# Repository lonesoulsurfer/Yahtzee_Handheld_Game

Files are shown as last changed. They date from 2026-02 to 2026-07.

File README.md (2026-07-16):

# Yahtzee - Handheld Game with an Optimal AI Brain

YouTube - https://youtu.be/DMBQGAXjRF4

Instructables - https://www.instructables.com/Yahtzee-Raspberry-Pi-Handheld-Game/

EKBK0852
RZYY5395
JPOU3428

---

## Two Versions of the Firmware

There are two versions of the game engine's "brain", and both are available to download and try from this repo:

- **V1, the Machine Learning brain.** The original approach: hand-built heuristics, probability tables, and a set of weighted priorities that adjust over time through self-play, stored in EEPROM. See the [V1 Overview](#v1-overview-the-machine-learning-brain) below.
- **V2, the Optimal "V-Brain".** The current version, and the one the rest of this README focuses on. It replaces the learned weights with an exact, mathematically solved decision table. See [How V2 Works](#how-v2-works-the-optimal-v-brain) below.

Both firmware versions are fully playable and included in this repo (`Yahtzee_v1.ino` / `Yahtzee_v2.ino`) if you want to compare them, or if you just prefer the adaptive feel of V1.

---

## V1 Overview: The Machine Learning Brain

V1 started out rule based, then grew into a probability and weights system. It uses hardcoded probability tables (for straights and of-a-kinds) to work out expected value, then adjusts its priorities, things like Yahtzee chasing, upper bonus feasibility, and endgame aggression, using a set of learned weights. Those weights live in EEPROM and shift over time based on self-play (the "Train AI" tool runs four personality variants against each other) and on how the human opponent plays.

It's a genuinely adaptive system. It gets tougher the more you play it, and it reads your playing style to adjust its own. But it's still fundamentally an approximation: the weights are a best guess at what matters in a given situation, tuned by trial and error rather than worked out from the actual maths of the game, and it needs a run-up of games before its learned behaviour is any good.

---

## How V2 Works: The Optimal V-Brain

V2 throws out the heuristics and weights entirely and replaces them with an exact solution, worked out once using dynamic programming and baked into a lookup table (`vtable.h`) that ships with the firmware. Rather than estimating the best move, V2 looks up the true expected value of every possible decision for the exact game state it's in, and simply picks the best one.

### The Value Table

`vtable.h` contains a solved value for every combination of:
- Which of the 13 scoring categories are still open (the "scorecard mask")
- The current upper section running total (capped at 63, since anything beyond that doesn't matter to the bonus)
- Whether a Yahtzee has already been scored (which changes what future Yahtzees are worth, thanks to the 100 point bonus)

For any of those states, the table gives the true expected final score from that point onward, assuming optimal play. This was worked out offline by starting from the end of the game and working backwards (a classic dynamic programming approach), so every value in the table is provably correct, not estimated.

### Making a Decision

On every roll, the V-brain does the following:
1. Sorts the current dice and looks up which of the 252 possible dice states it's in.
2. For each way it could hold some subset of the dice, works out the expected value of rerolling the rest, by weighting every possible reroll outcome by its true probability and looking up the resulting value in the table.
3. Compares that against simply stopping and scoring the best available category right now.
4. Picks whichever option has the higher expected value. No weights, no priority list, just the actual numbers.

This same lookup approach handles category selection too. Once the game engine stops rolling, it checks the value of scoring in every open category and takes the one with the highest true expected value, correctly accounting for the upper section bonus and the cost of spending a good category on a mediocre roll.

### Why It's Better

V1's weights can only ever approximate optimal play, and they need games (and EEPROM wear) to converge toward something good. V2's table already is the optimal policy. There's nothing to learn or converge toward, so it plays at maximum strength from the very first roll of the very first game, every single game. The trade-off is that V2 no longer profiles or adapts to a specific human opponent the way V1's learning system did. It isn't trying to be adaptive, it's trying to be correct.

### Still Carried Over from V1

A few things didn't need reinventing, so V2 keeps them as is:
- **Timeout protection.** If the game engine takes more than 30 seconds to decide, a watchdog forces it to pick the best available category and resets its state, so the game can never hang.
- **Stats tracking.** Win/loss history, high scores, and Yahtzee counts are still tracked and stored in EEPROM for the stats screens, even though none of it feeds back into how the V-brain plays.

---

## A Note on God Mode / Difficulty

V1's Normal / Hard / God Mode difficulty levels changed how aggressively the game engine would reroll. In V2, difficulty no longer changes how the AI plays. The V-brain always plays the mathematically optimal move, since there's no such thing as a "more optimal than optimal" setting. It is still beatable, since Yahtzee has a meaningful luck component, but you're playing against the best possible strategy on every roll.

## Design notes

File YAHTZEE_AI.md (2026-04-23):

# How the Yahtzee AI Works

When I first went on the journey to add a Player 1 vs the Computer mode, I didn't think it would take me down such a deep rabbit hole. The game of Yahtzee is a game of subtle nuances that revealed themselves to me when I tried (and still trying) to make an AI **God Mode** — an unbeatable opponent that always knows the right rolls and holds, and could use probability, strategy and learned weights to never lose.

The below is an outline of where I am currently.

---

## In a Nutshell

The AI holds dice based on what it's closest to completing, always thinking about whether the potential reward is worth the risk of rerolling. It respects special categories like Yahtzee and Large Straight enough to keep chasing them even late in a roll. It gets smarter the more you play against it, gradually learning what tends to win and adjusting its priorities accordingly. And at higher difficulties, it's simply more willing to gamble on a better outcome rather than accepting a safe but mediocre score.

---

## The Big Picture

The AI isn't just picking randomly or following a simple checklist. It's constantly asking itself two questions on every turn:

> *"Which dice should I keep?"*
> *"Is what I have now worth stopping for, or should I roll again?"*

Everything it does flows from trying to answer those two questions as smartly as possible.

---

## How It Decides Which Dice to Hold

Think of the AI like a card player who's always looking at their hand and asking *"what am I closest to completing?"* It looks at the dice and runs through a mental checklist, roughly in this order:

1. **Is the game almost over?** If there are only 2–3 scoring boxes left to fill, it stops being flexible and commits completely to whatever it still needs — chasing a Yahtzee, holding a straight sequence, or locking in pairs for a Full House. Crucially, it uses the actual remaining categories to decide what to hold — it won't hold two different numbers if neither remaining category can use them.

2. **Are we close to the upper section bonus?** The +35 bonus for scoring 63+ points in the top half of the scorecard is huge. If the AI is getting close, it'll often prioritise holding dice that help fill those upper boxes (Ones through Sixes), even if it means passing on something flashy.

3. **What's the best hand it's sitting on?** It looks at whether it has four-of-a-kind, three-of-a-kind, a pair, or a run of consecutive numbers, and figures out which is worth developing. It doesn't just hold the *"most dice"* — it asks which hand is actually worth the most if completed. Four 1s sounds like a lot to hold, but if the Ones box is already filled and Yahtzee is still available, it'll go for Yahtzee instead.

> **Key rule:** Pairs beat nothing, but a straight run beats a pair. If you have `2-3-4-5` showing, the AI will completely ignore any pair and hold the run, because straights are worth a flat 30 or 40 points — more predictable and often more valuable than building three-of-a-kind from a low pair.

---

## Probability Tables and Expected Value

Rather than using gut feel, the AI uses hardcoded probability tables to calculate the exact odds of completing any hand from its current dice. These are precomputed two-dimensional tables:

| Table | Description |
|---|---|
| **Of-a-Kind** | Probability of hitting 2-, 3-, 4-, or 5-of-a-kind when rerolling a specific number of dice (e.g. holding 3-of-a-kind and rerolling 2 dice has ~7.4% chance of hitting 5-of-a-kind in one roll) |
| **Large Straight** | Probability of completing a Large Straight based on how many values are still missing and how many rolls remain |
| **Small Straight** | Same as above for Small Straight |

For each possible way to hold the dice, the AI computes an **Expected Value (EV)** — the average score it can realistically expect if it plays that way. It then picks whichever hold pattern produces the highest EV, adjusted by the learned weights described below. This EV approach is the core engine; everything else either feeds into it or overrides it when warranted.

---

## Locked Decisions: When EV Doesn't Apply

Some situations are so mathematically clear that the AI locks the decision before any EV comparison or opponent-model adjustment is allowed to interfere:

- **4-of-a-kind with Yahtzee open** → Always reroll the 5th die
- **3-of-a-kind with Yahtzee open (or high value)** → Always hold the triple and chase the 4th (and potentially 5th) match
- **Yahtzee or Large Straight already in hand** → Always stop
- **Small Straight in hand with Large Straight already used** → Always stop and bank the guaranteed 30 points

These decisions set a `decision made` flag that prevents any downstream logic — conservative overrides, endgame risk adjustments, trailing/leading adjustments — from cancelling them.

---

## How It Decides Whether to Roll Again

- **After the first roll**, it almost always rerolls. Unless it rolled a Yahtzee or Large Straight right out of the gate, it's rolling again. There's also a minimum score floor: on the first roll, the AI won't stop unless it has 35+ points in hand (40+ on God Mode).

- **After the second roll**, it gets more selective. A confirmed Full House or solid upper box score is enough to stop — but four-of-a-kind with Yahtzee available, or four in a row with Large Straight available, always earns that third roll.

- **It also reads the score.** If the AI is losing by a decent amount, it plays more aggressively. If it's comfortably ahead, it locks in reliable points.

### Difficulty Margins

| Difficulty | Reroll Condition |
|---|---|
| **Normal** | EV of rerolling must exceed current score by at least 3 points |
| **Hard** | EV must match or exceed current score (break-even is enough) |
| **God Mode** | Will reroll even if EV is slightly *lower* — always chasing the maximum |

---

## The Three Difficulty Levels

| Level | Style | Base Aggression |
|---|---|---|
| **Normal** | Solid but forgiving. Stops if it has a decent score, won't chase long shots. | 0.35 |
| **Hard** | More aggressive. Willing to reroll a decent hand for something better. Uses learned data to adjust aggressiveness dynamically. | 0.65 |
| **God Mode** | Almost never stops after one roll. Squeezes every last roll out of every turn. Very tough to beat consistently. | 0.95 |

---

## Exploration vs Exploitation

About **10% of games**, the AI deliberately plays differently from its learned "best" strategy — this is an **exploration game**. It picks a random strategy (conservative or aggressive) with a randomised aggressiveness weight between 0.3 and 0.9.

The other **90% of games** it sticks to what's been working best — this is **exploitation**.

This balance ensures the AI doesn't get permanently stuck doing the same thing if something slightly different would actually work better.

---

## How It Learns Over Time

This is where it gets interesting — the AI actually remembers how past games went and slowly adjusts its behaviour. All learning data is saved to the device's **EEPROM** (non-volatile flash memory), so it persists even after you turn it off. A checksum is stored alongside the data so the device can detect and recover from any corruption.

Here's what it tracks and learns from:

- **What scores tend to lead to wins** — If games where it scores a Large Straight tend to go well, it prioritises Large Straights more. These preferences are stored as weight values per category type.

- **Confidence scaling** — Each weight adjustment is scaled by how many data points back it up. A weight based on 50 games carries four times more authority than one based on 5 games.

- **Whether rerolling was worth it — by score bracket** — It tracks reroll outcomes in four buckets (0–9, 10–19, 20–29, 30+) and builds a picture of when rerolling pays off in each bracket.

- **How each specific hold pattern performs** — For every combination of dice value and count held (e.g. *"held two 5s"*, *"held three 6s"*), it records how often that pattern led to a score of 20 or more. Tracked in a 6×6 grid (values 1–6 × counts 1–5).

- **When chasing Yahtzee or straights historically pays off** — Separate success rate counters track every attempt and completion. If Yahtzee success rate falls below 12%, it tightens the entry threshold (only chases with 3+ matching dice). If it climbs above 28%, it gets more aggressive (will chase from just a pair with 2 rolls left).

- **Which hold count works best (0–5 dice held)** — Tracked and displayed in the stats screen; informs the big picture of how the AI is playing.

- **Endgame close-game outcomes** — From turn 11 onwards, if the game is within 20 points, the AI records whether it won or lost. If its close-game win rate falls below 45%, it becomes more aggressive in the final turns.

- **Chance category timing** — Chance is most valuable early when all other slots are open. The AI tracks when it scores Chance (turns 1–3, 4–6, 7–9, or 10–13) and how often each timing leads to a win.

- **Score position at turn 10** — Tracked as a running average of (AI score minus human score) at the halfway point. If the AI is consistently 20+ points behind at turn 10, it raises aggression on early rerolls.

- **Category timing** — For each of the 13 scoring categories, the AI tracks the average turn it tends to score that category and uses this to inform future category priority.

- **Your playing style** — The AI quietly tracks how you play:
  - How often you hit the upper bonus
  - How many Yahtzees you roll
  - How aggressive you are (reroll rate and chase attempts)
  - Your average score

  Against a **strong player** (avg. score over ~250) it plays harder, rerolling on scores it might otherwise accept. Against a **conservative player** it locks in moderate scores more readily. If you frequently score Yahtzees, the AI prioritises chasing its own Yahtzee more urgently.

---

## The Four Strategies It Tests Against Itself

When you use the **Train AI** option in the Tools menu, the AI plays against itself using four different personalities:

| Strategy | Style |
|---|---|
| **Aggressive** | Goes hard for Yahtzees and big straights, willing to sacrifice safe points |
| **Balanced** | Uses whatever it's currently learned as its best approach |
| **Conservative** | Prioritises guaranteed points and the upper bonus over risky special hands |
| **Experimental** | A slightly randomised version, trying things a bit differently each time |

After each batch of self-play games, it looks at which personality won the most and nudges its main strategy in that direction. It's a slow process — you won't see it transform overnight — but over dozens of games it genuinely does shift toward what's been working.

Each strategy variant stores its own set of 8 weight values alongside its performance record (wins, games played, total score). It mostly picks the variant with the best recent win rate, but occasionally gives the others a shot so they can keep accumulating data.

---

## Category Selection

Once the AI has decided to stop rolling, it chooses which scoring category to use:

- It calculates an **expected value for every open category** given the current dice.
- **Upper section categories** are weighted by a bonus feasibility score — if the 35-point bonus is still realistically achievable, upper slots get a boost proportional to how much they contribute toward hitting 63.
- It considers **opportunity cost** — using a high-value slot (like Sixes) for a weak result is penalised more than using a low-value slot (like Ones) for the same score.
- In the **final 1–2 turns**, category selection becomes critical: it won't squander a Yahtzee chase on a 3-of-a-kind slot, and it won't take Chance if a more targeted category is still reachable.

---

## What Gets Displayed in the Stats Screens

The **AI Statistics screen** (accessible from the Tools menu) shows six pages of data including:

- Overall win rate and score history
- Reroll improvement rates per score bracket
- Hold pattern frequency
- Endgame win rates in close games and blowouts
- The four strategy variant performances
- Chance category timing
- Turn-10 score position history
- Current live values of all 8 learned weights

The graphs also track early-game vs recent-game average score so you can see whether the AI is improving over time.

---

## Timeout Protection

If the AI ever gets into an unexpected state and takes more than **30 seconds** to make a decision, a watchdog timer forces it to pick the best available category immediately and resets its state. This prevents the game from ever hanging.

---

## A Note on God Mode

God Mode is the closest the AI gets to theoretically optimal Yahtzee play. It uses maximum aggression, the full probability tables, all learned weights, and never applies conservative overrides.

It **is** beatable — Yahtzee has a meaningful luck component — but it will consistently make the highest expected value decision available to it on every single roll.

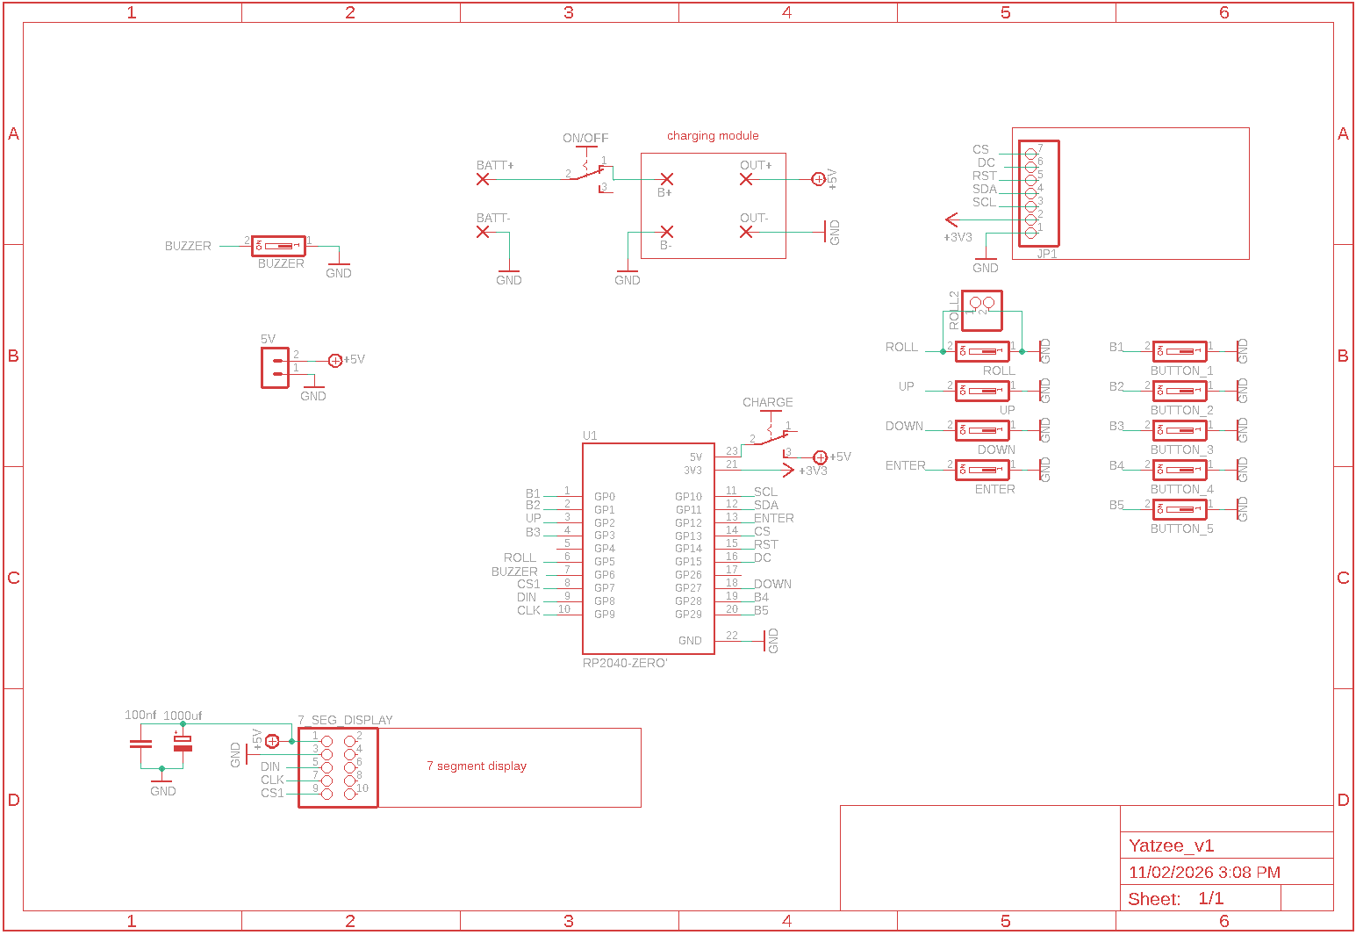
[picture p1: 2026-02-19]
Yahtzee - Schematic.png

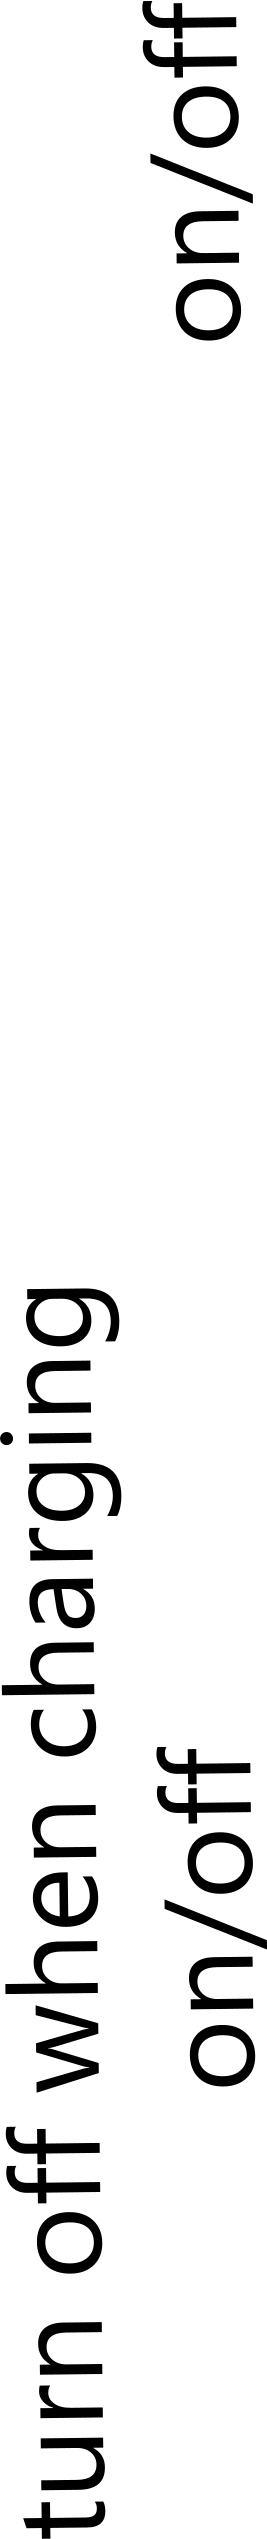
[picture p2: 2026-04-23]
Panel_Design/Back Panel/Yahtzee - Back Panel Inkscape.png

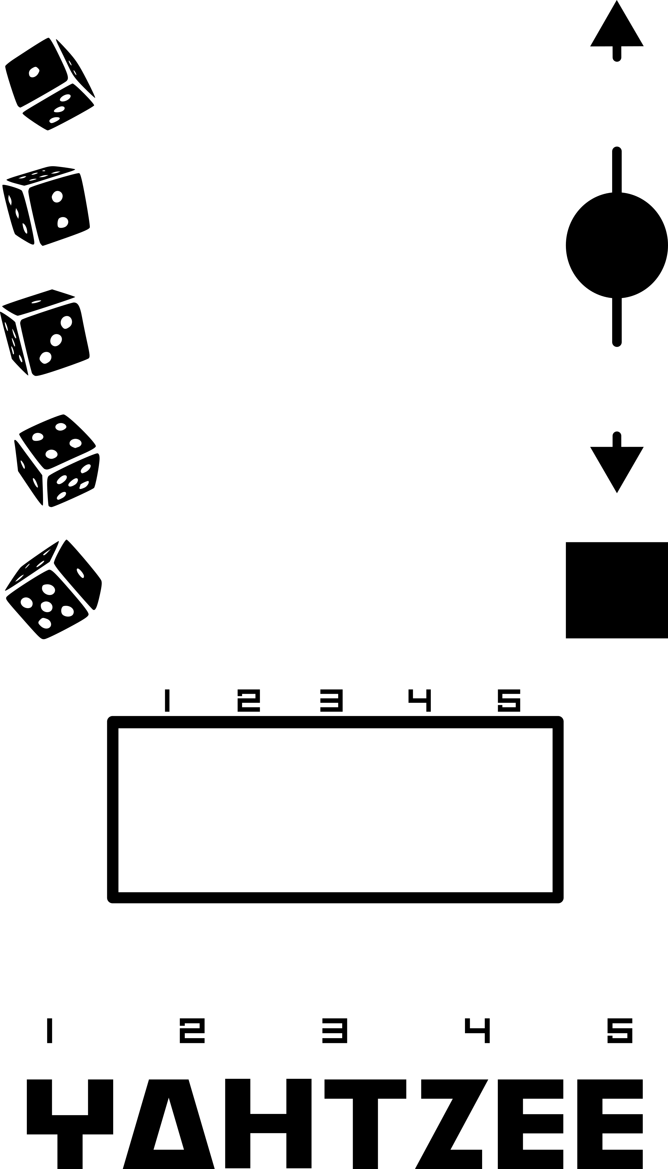
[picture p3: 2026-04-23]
Panel_Design/Front Panel/Front_Panel/Front Panel - Inkscape.png

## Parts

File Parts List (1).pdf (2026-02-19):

Part | Type | Part Number | Qty | Link | Image
Raspberry Pi Pico Zero | | | 1 | Link (https://www.aliexpress.com/w/wholesale-Raspberry-PI-Pico-Mini-RP2040%2525252dZERO-Microcontroller.html) Link (https://www.aliexpress.com/item/32949954569.html?curPageLogUid=Z8zhaCP7cIt1) Link (https://www.aliexpress.com/w/wholesale-TFT-Display-2.0-inch-OLED-LCD-Drive-IC-ST7789V-240.html)
Buzzer | Passive | | 1

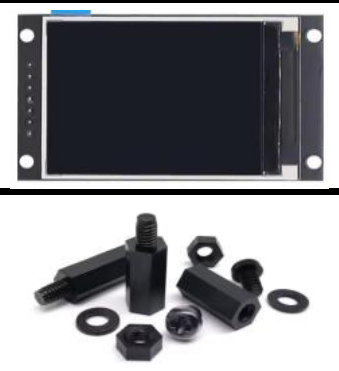
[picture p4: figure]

TFT Display | 2.0 inch OLED LCD Drive IC 240 x 320 | ST7789V | 1
Nylon Hex Spacers | M2 - assorted | | 1 | Link (https://www.aliexpress.com/item/1005007123661699.html)
Hex Socket Screw Kit | Ms - Assorted | DIN912 | 1 | Link (https://www.aliexpress.com/item/1005007273134914.html?curPageLogUid=XMboOUAJHQU8)
Battery | Lipo - (Mobile) | ab463446bu | 1 | Link (https://www.aliexpress.com/w/wholesale-ab463446bu.html?spm=a2g0o.detail.search.0)

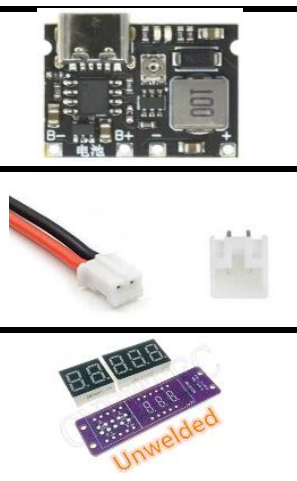
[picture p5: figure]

Charging & Voltage Module | 3.7V To 9V 5V 2A DC-DC Step Up Boost Modul | | 1 | Link (https://www.aliexpress.com/item/1005005656423941.html?srcSns=sns_More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)
Mini JST Connector and wire | 2 Pin | 1 | Link (https://vi.aliexpress.com/item/1005005939956886.html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)
7 segment display | 5 digit | 1 | Link (https://www.aliexpress.com/item/1005008537770484.html)

Part | Type | Part Number | Qty | Link | Image
Switches | Momentary. You can just use the reds ones if you want | SKRCADD010 | 7 | Link (https://www.aliexpress.com/w/wholesale-SKRCADD010.html?spm=a2g0o.productlist.search.0)
| | | 2 | Link (https://www.aliexpress.com/item/1005002904652943.html)
| slide | MSK-12D19 | 2 | Link (https://www.aliexpress.com/item/32828124825.html)
Capacitor | Polyester | 100nf | 1 | Link (https://vi.aliexpress.com/w/wholesale-capacitor-100nf.html?spm=a2g0o.productlist.search.0)
| Electrolytic | 1000uf | 1 | Link (https://www.aliexpress.com/item/1005007172225164.html?curPageLogUid=ffqTkzvnJ7Ic)
Header Pins | Female - short profile 7 rows | | | Link (https://www.aliexpress.com/item/1005004122312694.html)
| Male 7 rows | | | Link (https://www.aliexpress.com/w/wholesale-header-pin-male.html?spm=a2g0o.detail.search.0)

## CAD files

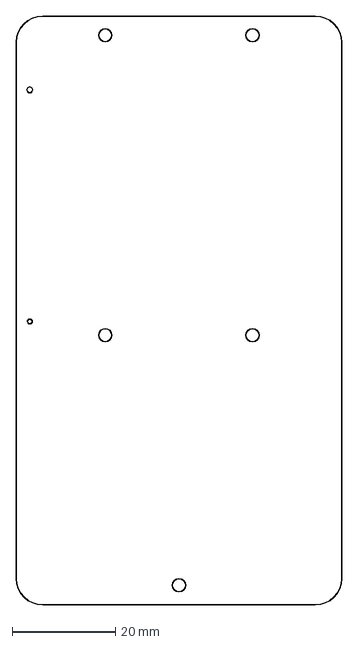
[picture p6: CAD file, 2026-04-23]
Panel_Design/Back Panel/Yatzee_PCB Back Panel Fusion.dxf
63.0 x 114.0 mm

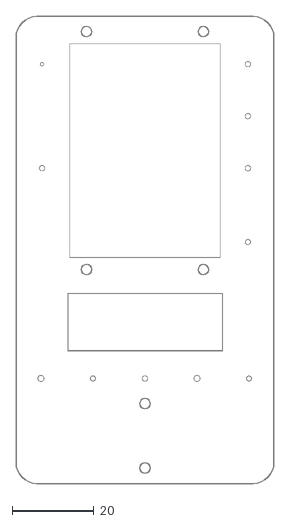
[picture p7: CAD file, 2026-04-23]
Panel_Design/Front Panel/Front_Panel/Yatzee PCB.dxf
63.0 x 114.0

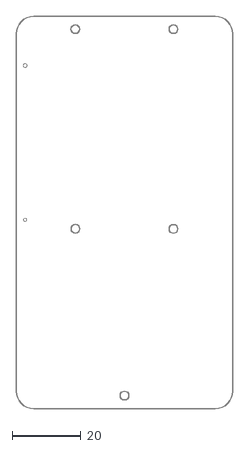
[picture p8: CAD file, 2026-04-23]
Panel_Design/Back Panel/Yatzee_PCB Back Panel.dxf
63.0 x 114.0

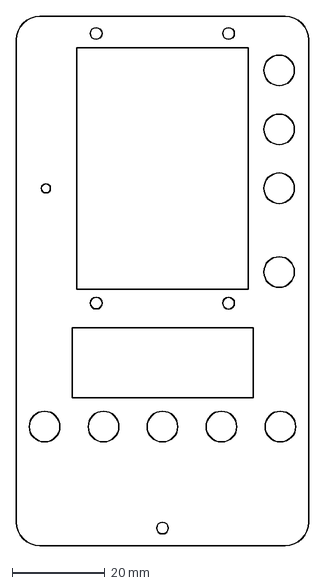
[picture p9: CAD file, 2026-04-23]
Panel_Design/Front Panel/Front_Panel/Yatzee Fusion.dxf
63.0 x 114.0 mm

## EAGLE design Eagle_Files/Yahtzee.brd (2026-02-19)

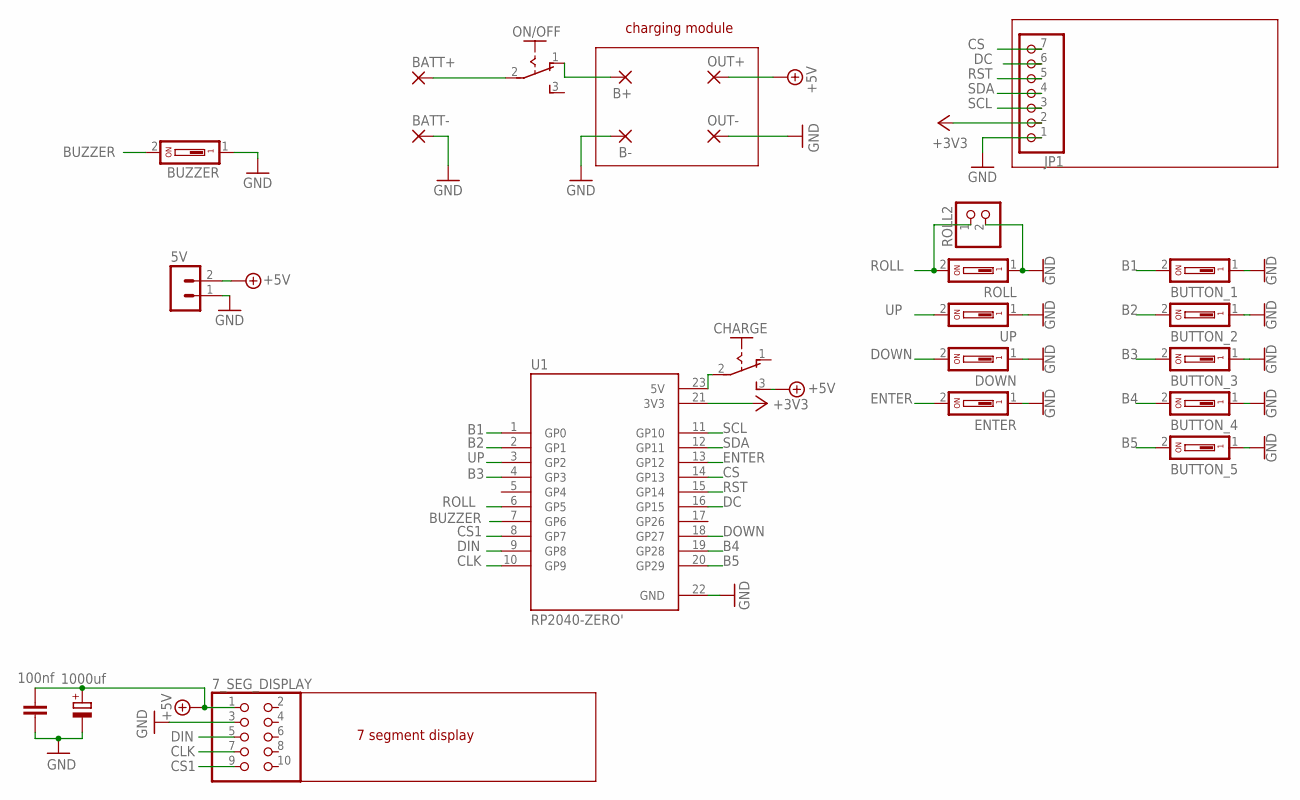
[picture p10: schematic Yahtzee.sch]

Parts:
5V: B2B-PH-K-S
7_SEG_DISPLAY: PINHD-2X5; 2X05
B+: SMD5; SMD2,54-5,08
B-: SMD5; SMD2,54-5,08
BATT+: SMD5; SMD2,54-5,08
BATT-: SMD5; SMD2,54-5,08
BUTTON_1, BUTTON_2, BUTTON_3, BUTTON_4, BUTTON_5: DS01; DS-01
BUZZER: DS01; DS-01
C1: 100nf; C050-024X044
C2: 1000uf; E2,5-7
CHARGE: M251
DOWN: DS01; DS-01
ENTER: DS01; DS-01
JP1: PINHD-1X7; 1X07
ON/OFF: M251
OUT+: SMD5; SMD2,54-5,08
OUT-: SMD5; SMD2,54-5,08
ROLL: DS01; DS-01
ROLL2: PINHD-1X2; 1X02
U1: RP2040-ZERO'; MODULE_RP2040-ZERO
UP: DS01; DS-01

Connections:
+3V3: JP1.2, U1.21 (3V3)
+5V: 5V.2, 7_SEG_DISPLAY.1, C1.1, C2.+, CHARGE.3 (S), OUT+.1
B1: BUTTON_1.2, U1.1 (GP0)
B2: BUTTON_2.2, U1.2 (GP1)
B3: BUTTON_3.2, U1.4 (GP3)
B4: BUTTON_4.2, U1.19 (GP28)
B5: BUTTON_5.2, U1.20 (GP29)
BUZZER: BUZZER.2, U1.7 (GP6)
CLK: 7_SEG_DISPLAY.7, U1.10 (GP9)
CS: JP1.7, U1.14 (GP13)
CS1: 7_SEG_DISPLAY.9, U1.8 (GP7)
DC: JP1.6, U1.16 (GP15)
DIN: 7_SEG_DISPLAY.5, U1.9 (GP8)
DOWN: DOWN.2, U1.18 (GP27)
ENTER: ENTER.2, U1.13 (GP12)
GND: 5V.1, 7_SEG_DISPLAY.3, B-.1, BATT-.1, BUTTON_1.1, BUTTON_2.1, BUTTON_3.1, BUTTON_4.1, BUTTON_5.1, BUZZER.1, C1.2, C2.-, DOWN.1, ENTER.1, JP1.1, OUT-.1, ROLL.1, ROLL2.2, U1.22 (GND), UP.1
unnamed: BATT+.1, ON/OFF.2
unnamed: B+.1, ON/OFF.1 (O)
unnamed: CHARGE.2, U1.23 (5V)
ROLL: ROLL.2, ROLL2.1, U1.6 (GP5)
RST: JP1.5, U1.15 (GP14)
SCL: JP1.3, U1.11 (GP10)
SDA: JP1.4, U1.12 (GP11)
UP: U1.3 (GP2), UP.2

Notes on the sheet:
charging module
7 segment display

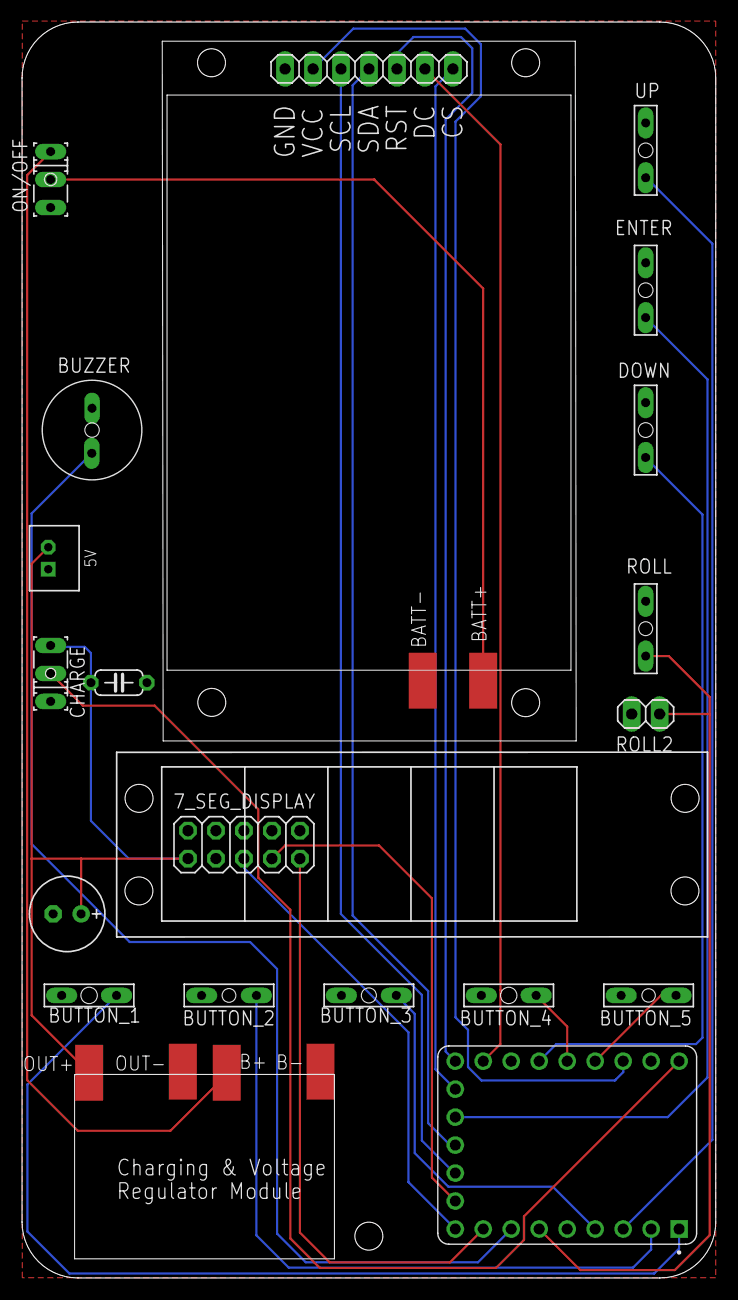
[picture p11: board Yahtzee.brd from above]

Board: 2 copper layers, 63.0 x 114.0 mm, 25 parts (0 on the bottom side), 24 nets.

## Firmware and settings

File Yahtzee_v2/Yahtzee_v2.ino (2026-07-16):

/*
 * Gameplay:
 * - 2 players alternate turns
 * - Each turn: Roll dice up to 3 times
 * - Hold dice between rolls with buttons 1-5
 * - After rolls, select scoring category
 * - Game ends after 26 turns (13 categories × 2 players)
 */

#include <SPI.h>
#include <Adafruit_GFX.h>
#include <Adafruit_ST7789.h>
#include <EEPROM.h>
#include "vtable.h"   // Optimal Yahtzee value table (option B). Must be in the sketch folder.

// ============================================================================
// BLACKJACK TYPES — defined here so Arduino prototype-generator sees them
// ============================================================================

struct Card {
  uint8_t value;  // 1=Ace 2-10 11=J 12=Q 13=K
  uint8_t suit;   // 0=Spades 1=Hearts 2=Diamonds 3=Clubs
};

const char* bjValueNames[] = {"A","2","3","4","5","6","7","8","9","10","J","Q","K"};

#define BJ_MAX_CARDS 11   // max cards in one BJ hand (same as original MAX_HAND)
#define MAX_HAND BJ_MAX_CARDS  // keep original name working in BJ file

int  bjDeckIndices[52];
int  bjDeckTop = 0;

Card bjPlayerHand[BJ_MAX_CARDS];
Card bjCompHand[BJ_MAX_CARDS];
Card bjSplitHand[BJ_MAX_CARDS];
int  bjPlayerCount = 0;
int  bjCompCount   = 0;
int  bjSplitCount  = 0;

enum BJGameState {
  BJ_STATE_MENU,
  BJ_STATE_BETTING,
  BJ_STATE_SIDEBET,
  BJ_STATE_PLAYER_TURN,
  BJ_STATE_COMP_TURN,
  BJ_STATE_RESULT,
  BJ_STATE_GAMEOVER
};

// Alias for side-bet screen (BJ file may reference BJ_STATE_SIDE_BETS)
#define BJ_STATE_SIDE_BETS BJ_STATE_SIDEBET

enum BJHandResult {
  BJ_RES_NONE,
  BJ_RES_PLAYER_BJ,
  BJ_RES_COMP_BJ,
  BJ_RES_PLAYER_WIN,
  BJ_RES_COMP_WIN,
  BJ_RES_PUSH,
  BJ_RES_PLAYER_BUST,
  BJ_RES_COMP_BUST
};

#define BJ_SB_COUNT 3

// ── EXACT EV LOOKUP TABLE (precomputed, 9.6KB flash) ─────────────────
// Auto-generated exact EV lookup table
// 252 dice states × 13 categories × 3 roll counts
// Values are EV × 2 (uint8, precision 0.5pts, max 50pts)
// State index: use lookupStateIndex(sorted_dice)

// Sorted dice states (for index lookup)
const uint8_t EV_STATES[252][5] = {
  {1,1,1,1,1},
  {1,1,1,1,2},
  {1,1,1,1,3},
  {1,1,1,1,4},
  {1,1,1,1,5},
  {1,1,1,1,6},
  {1,1,1,2,2},
  {1,1,1,2,3},
  {1,1,1,2,4},
  {1,1,1,2,5},
  {1,1,1,2,6},
  {1,1,1,3,3},
  {1,1,1,3,4},
  {1,1,1,3,5},
  {1,1,1,3,6},
  {1,1,1,4,4},
  {1,1,1,4,5},
  {1,1,1,4,6},
  {1,1,1,5,5},
  {1,1,1,5,6},
  {1,1,1,6,6},
  {1,1,2,2,2},
  {1,1,2,2,3},
  {1,1,2,2,4},
  {1,1,2,2,5},
  {1,1,2,2,6},
  {1,1,2,3,3},
  {1,1,2,3,4},
  {1,1,2,3,5},
  {1,1,2,3,6},
  {1,1,2,4,4},
  {1,1,2,4,5},
  {1,1,2,4,6},
  {1,1,2,5,5},
  {1,1,2,5,6},
  {1,1,2,6,6},
  {1,1,3,3,3},
  {1,1,3,3,4},
  {1,1,3,3,5},
  {1,1,3,3,6},
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
};

// EV table: [state_index][category][rolls_remaining]
// Category: 0-5=upper, 6=3K, 7=4K, 8=FH, 9=SmSt, 10=LgSt, 11=Ytz, 12=Chance
// Rolls: 0=must score now, 1=one roll left, 2=two rolls left
// ─────────────────────────────────────────────────────────────────────


BJGameState  bjGameState  = BJ_STATE_MENU;
BJHandResult bjHandResult = BJ_RES_NONE;

int      bjCredits       = 200;
int      bjBet           = 10;
uint32_t bjHandsPlayed   = 0;
int      bjPlayerWins    = 0;
int      bjCompWins      = 0;
int      bjPushes        = 0;
uint32_t bjLifetimeWon   = 0;
uint32_t bjLifetimeBet   = 0;
bool     bjPlayerIsDealer = true;
int      bjLastPayout    = 0;
int      bjLastNetResult = 0;
int      bjBiggestWin    = 0;
bool     bjDoubledDown   = false;
bool     bjIsSplit       = false;
int      bjSplitHandIdx  = 0;
int      bjSplitBet      = 0;
BJHandResult bjSplitResult = BJ_RES_NONE;

int  bjSideBetAmount[BJ_SB_COUNT] = {0, 0, 0};
int  bjSideBetPayout[BJ_SB_COUNT] = {0, 0, 0};
bool bjSideBetWon[BJ_SB_COUNT]    = {false, false, false};
int  bjSbSelected  = 0;
bool bjSbAdjusting = false;
BJGameState bjSbReturnState = BJ_STATE_BETTING;
const char* bjSbNames[BJ_SB_COUNT] = { "Perfect Pairs", "21 + 3", "Lucky Lucky" };

// REAL BJAILearning struct (fields match Blackjack_V1.ino exactly)
struct BJAILearning {
  uint16_t wins;
  uint16_t games;
  uint16_t hit16wins;
  uint16_t hit16total;
  uint16_t stand16wins;
  uint16_t stand16total;
  uint8_t  softAdj;
} aiData;


// ============================================================================
// PIN DEFINITIONS
// ============================================================================

// ST7789 TFT Display (Hardware SPI1)
#define TFT_CS     13  // GP13
#define TFT_RST    14  // GP14 (RES on display)
#define TFT_DC     15  // GP15
// Hardware SPI1 uses:
// MOSI (SDA) - GP11 (SPI1 TX) - already correct!
// SCLK (SCL) - GP10 (SPI1 SCK) - already correct!

// MAX7219 5-digit 7-segment display
#define DIN_PIN 8   // GP8 (swapped)
#define CLK_PIN 9   // GP9 (swapped)
#define CS_PIN  7   // GP7

// Buzzer
#define BUZZER_PIN 6   // GP6

// Button pins
const int holdButtons[] = {29, 28, 3, 1, 0};  // Hold dice 1-5 (reversed for 5-digit display)
const int rollButton = 5;        // GP5
const int upButton = 2;          // GP2
const int downButton = 27;       // GP27
const int enterButton = 12;      // GP12

#define EEPROM_BRIGHTNESS_ADDR 0  // EEPROM address for brightness storage
#define EEPROM_SOUND_ADDR 1       // EEPROM address for sound on/off
#define EEPROM_VOLUME_ADDR 11     // EEPROM address for volume (1 byte: 1-3)
#define EEPROM_HIGH_SCORE_ADDR 2  // EEPROM address for high score (2 bytes)
#define EEPROM_P1_WINS_ADDR 4     // EEPROM address for P1 wins (2 bytes)
#define EEPROM_P2_WINS_ADDR 6     // EEPROM address for P2 wins (2 bytes)
#define EEPROM_TIES_ADDR 8        // EEPROM address for ties (2 bytes)
#define EEPROM_MOST_YAHTZEES_ADDR 10  // EEPROM address for most Yahtzees in one game (1 byte)
#define EEPROM_AI_SPEED_ADDR 12       // EEPROM address for AI speed (1 byte: 0-3)
#define EEPROM_TFT_BRIGHTNESS_ADDR 13 // EEPROM address for TFT brightness (1 byte: 1-10)
#define EEPROM_AUTO_ADVANCE_ADDR 14   // EEPROM address for auto-advance (1 byte: 0/1)
#define EEPROM_AI_DIFFICULTY_ADDR 15  // EEPROM address for AI difficulty (1 byte: 0=Normal, 1=Hard, 2=God Mode)
#define EEPROM_AI_LEARNING_START 1000   // EEPROM address for AI learning data (moved far from other data)
#define EEPROM_STRATEGY_VARIANTS_ADDR 2048  // EEPROM address for 4 strategy variants (moved to 2048 to give AI data 1024 bytes)
#define EEPROM_AGGR_WEIGHT_ADDR 2112        // Per-difficulty aggressiveness weights: 3 bytes (Normal=0, Hard=1, God=2)
                                            // Stored as uint8_t * 100 (e.g. 0.65 → 65)

// ============================================================================
// DISPLAY INITIALIZATION
// ============================================================================

// Hardware SPI1 for TFT (much faster!)
Adafruit_ST7789 tft = Adafruit_ST7789(&SPI1, TFT_CS, TFT_DC, TFT_RST);

// ============================================================================
// GAME STATE VARIABLES
// ============================================================================

int dice[5];              // Current dice values (1-6)
bool held[5];             // Which dice are held
int currentPlayer = 1;    // Current player (1 or 2)
int rollsLeft = 3;        // Rolls remaining this turn
int rollsUsedThisTurn = 0;  // Track actual rolls used (1, 2, or 3)
int turn = 1;             // Current turn number (1-26)
int playerTurn = 1;       // Current player's turn number (1-13)
int scores1[13];          // Player 1 scores (-1 = unused)
int scores2[13];          // Player 2 scores (-1 = unused)
int yahtzeeBonus1 = 0;    // Player 1 Yahtzee bonus count
int yahtzeeBonus2 = 0;    // Player 2 Yahtzee bonus count
bool gameOver = false;    // Game finished flag
// Per-game roll count for AI: tracks how many times each roll-count (1/2/3)
// was used THIS game so rollCountWins credits the correct distribution.
uint16_t aiRollCountThisGame[4] = {0,0,0,0};  // indices 1-3 used


// UI state
enum GameState {
  STATE_INTRO,            // Animated intro screen (NEW!)
  STATE_MENU,             // Main menu (NEW!)
  STATE_START,            // Waiting to start turn
  STATE_ROLLING,          // Rolling dice phase
  STATE_CATEGORY_SELECT,  // Selecting score category
  STATE_GAME_OVER         // Game finished
};
GameState gameState = STATE_START;

// Menu state
int selectedMenuItem = 0;  // 0 = 2 Player, 1 = vs Computer, 2 = Tools
bool vsComputer = false;   // Track if playing against computer
bool inToolsMenu = false;  // Track if we're in the tools submenu
bool inSoundMenu = false;  // Track if we're in the sound submenu
bool inHelpMenu = false;   // Track if we're in the help/rules screen
bool inGraphMenu = false;  // Track if we're in the AI graphs screen
bool inAIDifficultyMenu = false;  // Track if we're in the AI difficulty selection menu
int selectedAIDifficulty = 1;  // Selected difficulty in the menu (0=Normal, 1=Hard, 2=God)
int helpPage = 0;          // Help screen page (0-2)
int toolsPage = 0;         // Tools menu page (0 = page 1, 1 = page 2)
int selectedToolItem = 0;  // 0=7seg, 1=sound, 2=auto-advance, 3=stats, 4=AI stats, 5=AI speed, 6=export, 8=graphs, 9=help, 10=back
int selectedSoundItem = 0; // 0 = Sound On/Off, 1 = Volume, 2 = Back
int aiStatsPage = 0;  // single AI Stats page
int graphPage = 0;    // Graph page: 0-5 for 6 enhanced analysis graphs
int max7219Brightness = 8;  // Brightness level (0-15, loaded from EEPROM in setup)
bool adjustingBrightness = false;  // Track if actively adjusting brightness
int tftBrightness = 10;     // TFT brightness level (1-10, loaded from EEPROM in setup)
bool adjustingTftBrightness = false;  // Track if actively adjusting TFT brightness
bool soundEnabled = true;  // Sound on/off (loaded from EEPROM in setup)
int volume = 2;  // Volume level (1-3, loaded from EEPROM in setup)
bool adjustingVolume = false;  // Track if actively adjusting volume
bool autoAdvance = false;  // Auto-advance to next turn after scoring (loaded from EEPROM in setup)

// Game over animation state
#define MAX_CONFETTI 40
struct Confetti {
  float x;
  float y;
  float speedY;
  float speedX;
  uint16_t color;
  bool active;
};
Confetti confetti[MAX_CONFETTI];
unsigned long gameOverStartTime = 0;
bool gameOverAnimationStarted = false;
float winnerTextScale = 0.0;  // For dramatic entrance
uint16_t winnerColorHue = 0;  // For color cycling

// Statistics variables
int highScore = 0;        // Highest score ever
int p1Wins = 0;           // Player 1 total wins
int p2Wins = 0;           // Player 2 total wins
int totalTies = 0;        // Total tied games
int mostYahtzees = 0;     // Most Yahtzees in one game
int currentGameYahtzees1 = 0;  // Yahtzees this game for P1
int currentGameYahtzees2 = 0;  // Yahtzees this game for P2
int aiDifficulty = 1;  // AI difficulty: 0 = Normal, 1 = Hard, 2 = God Mode
int aiSpeed = 2;  // AI speed: 0=Slow (5s), 1=Medium (3.5s), 2=Fast (2.5s), 3=Instant (0.5s)

// Per-game tracking for new decision-quality stats
int  aiChanceBucket           = -1;   // Which turn-bucket Chance was scored in (-1=not yet)
int  aiChanceVsUpperLastChoice = -1;  // 0=chose upper, 1=chose Chance, -1=no decision yet
bool aiSacrificedSlot[6]  = {false,false,false,false,false,false}; // Which upper slots were sacrificed
bool aiAheadAtTurn10      = false; // Was AI ahead at turn 10?
bool aiTurn10Recorded     = false; // Have we recorded turn-10 state this game?

// ============================================================================
// AI LEARNING SYSTEM
// ============================================================================

// AI Learning data structure - stores performance metrics in EEPROM
// Strategy variant structure - MUST be defined before AILearningData

// Analyze straight potential and return hold strategy


// Decision outcome tracking
struct DecisionOutcome {
  uint8_t turnNumber;        // Which turn (1-13)
  uint8_t rollNumber;        // Which roll (1-3)
  uint8_t diceHeld;          // How many dice held (0-5)
  uint8_t categoryScored;    // Which category was scored (0-12)
  uint8_t pointsScored;      // How many points
  bool wonGame;              // Did AI win this game?
  bool leadingWhenDecided;   // Was AI leading when decision made?
};

// Track last 100 decisions for pattern analysis
#define MAX_DECISION_HISTORY 100
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
void loop() {
  static unsigned long lastButtonCheck = 0;
  static unsigned long lastAnimFrame = 0;
  
  // Update intro animation at 60fps
  if(gameState == STATE_INTRO) {
    static bool startupMusicPlayed = false;
    static unsigned long introStartTime = 0;
    
    if(introStartTime == 0) {
      introStartTime = millis();
    }
    
    if(millis() - lastAnimFrame > 16) {  // ~60fps
      lastAnimFrame = millis();
      
      // Play startup music after 100ms delay (so dice are visible and falling)
      if(!startupMusicPlayed && millis() - introStartTime > 100) {
        buzzerStartupTune();
        startupMusicPlayed = true;
      }
      
      updateIntroAnimation();
      
      // Always redraw if not complete (to show title animation)
      if(!introComplete) {
        drawIntroScreen();
      } else {
        // Transition to menu after a short pause so YAHTZEE is readable
        static unsigned long completeTime = 0;
        static bool drewComplete = false;
        
        if(!drewComplete) {
          drawIntroScreen();
          completeTime = millis();
          drewComplete = true;
        } else if(millis() - completeTime > 600) {
          // After 600ms, go to menu
          gameState = STATE_MENU;
          startupMusicPlayed = false;
          introStartTime = 0;
          drewComplete = false;   // Reset for next time
          completeTime = 0;
          drawScreen();
        }
      }
    }
  }

  // Update dice animation
  if(diceAnimating) {
    updateDiceAnimation();
    delay(16);  // ~60fps for smooth animation
  }
  
  // Update celebration particles
  // CRITICAL: Never run celebration once game is over — it overwrites the scorecard
  if(celebrationActive && gameState == STATE_GAME_OVER) {
    celebrationActive = false;  // Kill any active celebration when game ends
  }
  if(celebrationActive) {
    updateCelebration();
    drawCelebration();  // Draw clean celebration screen with particles
    delay(16);  // ~60fps for smooth animation
  }
  
  // Continuously animate the game over screen (winner badge floats each frame)
  static unsigned long lastGameOverFrame = 0;
  if(gameState == STATE_GAME_OVER && !celebrationActive && millis() - lastGameOverFrame > 16) {
    lastGameOverFrame = millis();
    drawGameOver();
  }
  
  // Handle computer turn - trigger automatically when it's Player 2's turn
  // **CRITICAL**: Don't run computer turn during celebrations!
  if(vsComputer && currentPlayer == 2 && 
     gameState != STATE_GAME_OVER && gameState != STATE_INTRO && gameState != STATE_MENU &&
     !celebrationActive) {  // NEW: Don't interrupt celebrations
    computerTurn();
  }
  
  // Check buttons every 100ms (only for human player)
  if(millis() - lastButtonCheck > 100) {
    lastButtonCheck = millis();
    if(!computerIsThinking) {
      // Full button processing for human player
      checkButtons();
    } else {
      // During AI turn, still allow UP/DOWN for viewing scores
      checkViewButtons();
    }
    lastButtonCheck = millis();
  }
  
  // Check for game over
  if(gameOver && gameState != STATE_GAME_OVER) {
    gameState = STATE_GAME_OVER;
    drawScreen();
  }
}

// ============================================================================
// GAME INITIALIZATION
// ============================================================================

void initializeGame() {
  // Initialize dice (blank)
  for(int i = 0; i < 5; i++) {
    dice[i] = 0;  // 0 = blank
    held[i] = false;
  }
  
  // Initialize scores (-1 = unused)
  for(int i = 0; i < 13; i++) {
    scores1[i] = -1;
    scores2[i] = -1;
  }
  
  // Reset game state
  currentPlayer = 1;
  turn = 1;
  playerTurn = 1;
  rollsLeft = 3;
  rollsUsedThisTurn = 0;  // Reset roll counter
  gameOver = false;
  gameState = STATE_INTRO;
  selectedCategory = 0;
  menuScroll = 0;
  winnerCelebrationShown = false;  // Reset for new game
  currentGameYahtzees1 = 0;  // Reset Yahtzee counter
  currentGameYahtzees2 = 0;  // Reset Yahtzee counter
  statsUpdated = false;
  winnerFlashTimer = 0;      // Reset flash timer
  winnerFlashState = true;   // Reset flash state
  gameOverAnimationStarted = false;  // Reset game over animation
  gameOverStartTime = 0;
  winnerTextScale = 0.0;
  winnerColorHue = 0;
  // Reset per-game decision tracking flags
  aiChanceBucket   = -1;
  aiTurn10Recorded = false;
  aiAheadAtTurn10  = false;
  for(int s = 0; s < 6; s++) aiSacrificedSlot[s] = false;
  aiChanceVsUpperLastChoice = -1;  // -1=no decision, 0=chose upper, 1=chose Chance
  aiLastScoredCategory = -1;  // Reset score highlight
  for(int r = 0; r < 4; r++) aiRollCountThisGame[r] = 0;  // Reset per-game roll counter
  
  // Determine AI strategy for this game based on aggressiveness weight
// NEW: Epsilon-Greedy Exploration (10% of games)
float explorationRate = 0.10;  // 10% exploration
currentGameIsExploration = false;
  
if(vsComputer) {
  if(random(100) < explorationRate * 100) {
    // EXPLORATION: Try a random strategy
    currentGameIsExploration = true;
    currentGameStrategy = random(0, 2);  // Random: 0=conservative, 1=aggressive
    
    // Also randomize aggressiveness weight for this game
    aggressivenessWeight = random(30, 90) / 100.0;  // 0.3 to 0.9
    
  } else {
    // EXPLOITATION: Use learned strategy
    currentGameStrategy = (aggressivenessWeight > 0.6) ? 1 : 0;
  }
}

  initIntroAnimation();
  
  updateDiceDisplay();
}

// ============================================================================
// BUTTON HANDLING
// ============================================================================

// ============================================================================
// VIEW BUTTONS - Minimal button handling during AI turns
// ============================================================================

void checkViewButtons() {
  static bool lastUp = HIGH;
  static bool lastDown = HIGH;
  
  bool upBtn = digitalRead(upButton);
  bool downBtn = digitalRead(downButton);
  
  // UP button - toggle between upper and lower section view during AI turn
  if(lastUp == HIGH && upBtn == LOW) {
    if(gameState == STATE_ROLLING || gameState == STATE_CATEGORY_SELECT) {
      scoreViewSection = 1 - scoreViewSection;  // Toggle between 0 and 1
      drawScreen();
      buzzerMenuMove();
    }
  }
  lastUp = upBtn;
  
  // DOWN button - toggle between upper and lower section view during AI turn
  if(lastDown == HIGH && downBtn == LOW) {
    if(gameState == STATE_ROLLING || gameState == STATE_CATEGORY_SELECT) {
      scoreViewSection = 1 - scoreViewSection;  // Toggle between 0 and 1
      drawScreen();
      buzzerMenuMove();
    }
  }
  lastDown = downBtn;
}

// ============================================================================
// BUTTON HANDLING
// ============================================================================
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

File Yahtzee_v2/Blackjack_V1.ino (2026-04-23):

/*
 * BLACKJACK v3
 * Hardware: RP2040 (Raspberry Pi Pico or compatible)
 *   - ST7789 TFT 240x320 (Hardware SPI1: MOSI=GP11, SCK=GP10)
 *   - MAX7219 5-digit 7-segment display (DIN=GP8, CLK=GP9, CS=GP7)
 *   - Buzzer on GP6
 *   - 5 action buttons left→right: GP0, GP1, GP3, GP28, GP29
 *   - DEAL button GP5  |  UP GP2  |  DOWN GP27  |  ENTER GP12
 *
 * ┌─────────────────────────────────────────────────────┐
 * │  BUTTON GUIDE (5 physical buttons, left to right)   │
 * │  [1: HIT ] [2:STAND] [3: DBL] [4:SPLIT] [5:SIDE$]  │
 * │  DEAL button = also HIT   |   ENTER button = STAND  │
 * └─────────────────────────────────────────────────────┘
 *
 * CONTROLS:
 *   MENU        : DEAL = Start game | UP/DN = set bjCredits
 *                 DEAL hold 3s = Return to Tools menu | ENTER hold 3s = Reset stats
 *   BETTING     : UP/DN = Adjust bjBet | ENTER = Max bjBet | DEAL = Deal cards
 *                 Btn5 = Open side bets menu
 *   SIDE BETS   : UP/DN = scroll bets | ENTER = select/adjust | Btn5 = close
 *   PLAYER TURN : Btn1 or DEAL = HIT | Btn2 or ENTER = STAND | Btn3 = DOUBLE DOWN | Btn4 = SPLIT
 *   SPLIT TURN  : Btn1 or DEAL = HIT | Btn2 or ENTER = STAND (plays each split hand in turn)
 *   RESULT      : Auto-advances to next hand after 1 second (or press early)
 *   MENU 3s hold DEAL = Return to Tools menu | MENU 3s hold ENTER = Reset all stats
 *
 * SIDE BETS (persist hand-to-hand until removed, max 500 each):
 *   Perfect Pairs : Mixed pair 5:1 | Coloured pair 12:1 | Perfect pair 25:1
 *   21+3          : Flush 5:1 | Straight 10:1 | Three of a Kind 30:1
 *                   Straight Flush 40:1 | Suited Trips 100:1
 *   Lucky Lucky   : 19 or 20 total 2:1 | Unsuited 21 3:1 | Suited 21 15:1
 *                   6-7-8 or 7-7-7 100:1
 *
 * BLACKJACK RULES:
 *   - Closest to 21 without busting wins
 *   - Natural Blackjack (A + 10-value on first 2 cards) pays 3:2
 *   - Push (tie) returns your bjBet
 *   - Double Down: doubles your bjBet, you receive exactly one more card
 *   - Split: on equal-value first two cards, pay another bjBet, play two hands
 *   - Dealer (computer) hits soft 16 and below, stands on 17+
 *   - BJ DEALER ROLE: Player starts as dealer. If computer gets Blackjack it
 *     becomes dealer next hand. If player gets Blackjack, player takes dealer back.
 */


// ============================================================================
// PIN DEFINITIONS  (identical hardware to VideoPoker)
// ============================================================================




// Physical layout left→right: GP0, GP1, GP3, GP28, GP29
// Array index 4 = GP0 (leftmost), index 0 = GP29 (rightmost)
#define BTN_HIT_IDX    4   // leftmost  → GP0
#define BTN_STAND_IDX  3   // 2nd left  → GP1
#define BTN_DOUBLE_IDX 2   // middle    → GP3
#define BTN_SPLIT_IDX  1   // 4th left  → GP28
#define BTN_SIDEBET_IDX 0  // rightmost → GP29


// ============================================================================
// EEPROM ADDRESSES
// ============================================================================

#define EE_CREDITS_ADDR  450   // 2 bytes  (int)
#define EE_HANDS_ADDR  454   // 4 bytes  (uint32_t)
#define EE_P_WINS_ADDR  458   // 2 bytes  player wins
#define EE_C_WINS_ADDR  460   // 2 bytes  computer wins
#define EE_PUSHES_ADDR  462   // 2 bytes  bjPushes/ties
#define EE_BRIGHTNESS_ADDR  464  // 1 byte
#define EE_SOUND_ADDR  465   // 1 byte
#define EE_TOTAL_WON_ADDR  466  // 4 bytes
#define EE_TOTAL_BET_ADDR  470  // 4 bytes
#define EE_DEALER_ADDR  474   // 1 byte  0=player is dealer, 1=computer is dealer
// AI learning data
#define EE_AI_WINS_ADDR  476   // 2 bytes
#define EE_AI_GAMES_ADDR  478   // 2 bytes
#define EE_AI_HIT16_ADDR  480   // 2 bytes  times AI hit on 16 and won
#define EE_AI_H16T_ADDR  482   // 2 bytes  times AI hit on 16 (total)
#define EE_AI_STAND16_ADDR  484  // 2 bytes  times AI stood on 16 and won
#define EE_AI_S16T_ADDR  486   // 2 bytes  times AI stood on 16 (total)
#define EE_AI_SOFTADJ_ADDR  488  // 1 byte   soft-17 hit rate bias (0-255, 128=neutral)
#define EE_BIGGEST_WIN_ADDR  490 // 2 bytes  biggest net win

// ============================================================================
// DISPLAY
// ============================================================================


// ============================================================================
// COLOURS
// ============================================================================

#define C_BG          0x0821   // Very dark blue-black
#define C_TEXT        0xFFFF   // White
#define C_GREEN       0x07E0
#define C_LTGREEN     0x87F0
#define C_RED         0xF800
#define C_YELLOW      0xFFE0
#define C_ORANGE      0xFD20
#define C_CYAN        0x07FF
#define C_GRAY        0x7BEF
#define C_DARKGRAY    0x2965
#define C_GOLD        0xFEA0
#define C_DARKGOLD    0xB400
#define C_NAVY        0x000F
#define C_BLUE        0x001F
#define C_LTBLUE      0x04FF
#define C_MAGENTA     0xF81F
#define C_FELT        0x02A0   // Casino felt green
#define C_FELT_LT     0x04C0   // Lighter felt
#define C_CARD_WHITE  0xFFFF
#define C_RED_SUIT    0xE800
#define C_BLACK_SUIT  0x18C3
#define C_WIN_BG      0x0400
#define C_LOSE_BG     0x2000
#define C_PUSH_BG     0x18C3
#define C_HIGHLIGHT   0xFEA0   // Gold highlight border

// Card struct + deck vars + hand arrays defined in Yahtzee_v1.ino
// ============================================================================
// LAYOUT — Screen 240×320 portrait
// ============================================================================
// Pixel budget breakdown (must total 320):
//   0.. 21  Header bar        22px
//  22.. 40  Computer label    19px  (taller for size-2 score text)
//  41..100  Computer cards    60px
// 101..109  Mid result strip   9px
// 110..128  Player label      19px  (taller for size-2 score text)
// 129..188  Player cards      60px
// 189..220  Bottom info bar   32px  (bjBet + bjCredits on one row each, compact)
// 221..255  Hint bar          35px
// 256..319  Button guide bar  64px
// Total: 22+19+60+9+19+60+32+35+64 = 320 ✓

#define HDR_H         22
#define COMP_LBL_Y    22
#define COMP_LBL_H    19
#define COMP_CARD_Y   41
#define COMP_CARD_H   60
#define MID_SCORE_Y   101
#define MID_SCORE_H   9
#define PLAY_LBL_Y    110
#define PLAY_LBL_H    19
#define PLAY_CARD_Y   129
#define PLAY_CARD_H   60
#define PLAY_SCORE_Y  189
#define PLAY_SCORE_H  13
#define BOTTOM_Y      189
#define BOTTOM_H      67
#define BTN_BAR_Y     256
#define BTN_BAR_H     64

// Cards: 31px wide, 3px gap → 7 cards = 7*31+6*3 = 235px fits in 240 ✓
#define CARD_W   31
#define CARD_H   60
#define CARD_GAP  3
#define CARD_X0   2

// ============================================================================
// GAME STATE
// ============================================================================

// BJGameState enum defined in Yahtzee_v1.ino

// BJHandResult enum defined in Yahtzee_v1.ino




// ── Split state ──
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

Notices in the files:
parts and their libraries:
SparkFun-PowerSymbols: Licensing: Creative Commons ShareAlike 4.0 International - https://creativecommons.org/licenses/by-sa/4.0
